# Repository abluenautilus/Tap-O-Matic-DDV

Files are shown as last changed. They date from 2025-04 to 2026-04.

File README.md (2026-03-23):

# Tap-O-Matic DDV

The Olivia Artz Modular Time Machine, version by Harry Richardson, modified by Blue Nautilus and the DivKid Discord, and finally tweaked heavily by Eris Fairbanks. We've come full circle folks!

This version modifies the [Tap-O-Matic version](https://github.com/cormallen/tap-o-matic) by HR in two ways:
<ul>
<li>It moves the pan pots down by 2mm. This makes the build much easier since the pan pots don't butt up against the sliders.</li>
<li>It moves the power header on the back so that it doesn't interfere with one of the jacks. This means you don't have to shave plastic off the jack.</li>
</ul>

**Eris's Software Notes:**
- Read heads are paired in order to utilize the PSRAM cache more effectively.
- The dynamics management system is drastically improved, utilizing a 4-point lookahead system per read-head pair.
- Filters used to be one-poles, now they're my own SVF implementation. Steeper cutoff, more resonance, more character.
- Code is a bit more readable and cleaner I think, constants and twiddle factors gathered up and commented.
- CPU usage is better, though extreme time variation might still cause frame drops? I haven't seen any, but that doesn't mean they aren't possible. Might be good to bump block size up to 8 if we notice any.
- Feedback can still distort. Dynamic range still isn't what I'd like it to be and probably never will be unless there's a hardware change to support 20vpp.

## Front Panel

All of the files for producing the panels are in the panel folder. This panel was fabricated by http://pcbway.com. It's a PCB panel using matte black solder mask:



## BOM

Our modified BOM is here:
https://docs.google.com/spreadsheets/d/1hPb3Es_wUxIoNBYNVZt8cKr9BfJMghtDLR-cnE-fVQ0/edit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

## Fabrication Instructions

The fabrication guide can be found here: 

https://docs.google.com/document/d/1D_RPgzVUW2ujZSJS9yKFKmFV2mPIwQp9BS7iKvg6IVI/edit?tab=t.0

## Build Instructions

The build guide can be found here: 

https://docs.google.com/document/d/1rPKsOXEx5abdQNxCypnp2nViSWlIubEysEng-fZd7tw/edit?tab=t.0

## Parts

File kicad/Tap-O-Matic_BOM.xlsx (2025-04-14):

Id | Designator | Footprint | Quantity | Designation | Part# | Link | Price/Ea | TotalPrice
1 | R6,R7,R1,R9,R8,R5,R4,R3,R2 | PTL45 | 9 | 10K | PTL30-15R0-104B2 | https://www.mouser.com/ProductDetail/Bourns/PTL30-15R0-104B2?qs=b8viKDOLiXa94D7vjOKn0w%3D%3D | 1.87 | 16.83
2 | RV7,RV14,RV13,RV12,RV11,RV10,RV9,RV8,RV6 | SongHuei_tall_trimmer | 9 | 10K |  | https://www.thonk.co.uk/shop/ttpots/ | 1.22 | 10.98
3 | SW2,SW1 | SALECOM_ES4-2_SPDT | 2 | SW_SPDT |  | https://www.thonk.co.uk/shop/ttpots/ | 1.84 | 3.68
4 | U1 | DaisySubmodule | 1 | DaisySubmodule |  | https://electro-smith.com/products/patch-submodule | 24 | 24
5 | RSPREAD1,RLPF1,RHPF1,RFB1,RTIME1 | Potentiometer_Alpha_RD901F-40-00D_Single_Vertical | 5 | 10K |  | https://www.thonk.co.uk/shop/alpha-9mm-pots/ | 2.15 | 10.75
6 | C5,C4,C3,C2,C1 | C_Disc_D3.8mm_W2.6mm_P2.50mm | 5 | 100n |  |  |  | 0
7 | J16 | PinHeader_2x05_P2.54mm_Vertical | 1 | Conn_02x05_Odd_Even |  |  |  | 0
8 | U5 | DIP-16_W7.62mm_Socket | 1 | DG408 |  |  |  | 0
9 | U4,U3,U2 | DIP-16_W7.62mm_Socket | 3 | 4051 |  |  |  | 0
10 | R18,R17,R16,R15,R14,R13,R12,R11,R10 | R_Axial_DIN0207_L6.3mm_D2.5mm_P7.62mm_Horizontal | 9 | 1K |  |  |  | 0
11 | OUT_R1,OUT_L1,IN_R1,IN_L1,LPF1,HPF1,FB1,TIME1,SPREAD1,CLOCK1,J9,J8,J7,J6,J5,J4,J3,J2,J1 | thonkiconn_fuzzySi | 19 | fuzzySI_thonkiconn |  |  |  | 0
12 | U2, U3, U4, U6 | DIP-16_W7.62mm_Socket | 4 | 16-pin DIP sockets |  |  |  | 0
13 | U1 | 2x5 header | 4 | 2x5 headers |  |  |  | 0
Total |  |  |  |  |  |  |  | 66.24

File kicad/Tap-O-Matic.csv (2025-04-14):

Id | Designator | Footprint | Quantity | Designation | Supplier and ref
1 | R6,R7,R1,R9,R8,R5,R4,R3,R2 | PTL45 | 9 | 10K
2 | RV7,RV14,RV13,RV12,RV11,RV10,RV9,RV8,RV6 | SongHuei_tall_trimmer | 9 | 10K
3 | SW2,SW1 | SALECOM_ES4-2_SPDT | 2 | SW_SPDT
4 | U1 | DaisySubmodule | 1 | DaisySubmodule
5 | RSPREAD1,RLPF1,RHPF1,RFB1,RTIME1 | Potentiometer_Alpha_RD901F-40-00D_Single_Vertical | 5 | 10K
6 | C5,C4,C3,C2,C1 | C_Disc_D3.8mm_W2.6mm_P2.50mm | 5 | 100n
7 | J16 | PinHeader_2x05_P2.54mm_Vertical | 1 | Conn_02x05_Odd_Even
8 | U5 | DIP-16_W7.62mm_Socket | 1 | DG408
9 | U4,U3,U2 | DIP-16_W7.62mm_Socket | 3 | 4051
10 | R18,R17,R16,R15,R14,R13,R12,R11,R10 | R_Axial_DIN0207_L6.3mm_D2.5mm_P7.62mm_Horizontal | 9 | 1K
11 | OUT_R1,OUT_L1,IN_R1,IN_L1,LPF1,HPF1,FB1,TIME1,SPREAD1,CLOCK1,J9,J8,J7,J6,J5,J4,J3,J2,J1 | thonkiconn_fuzzySi | 19 | fuzzySI_thonkiconn

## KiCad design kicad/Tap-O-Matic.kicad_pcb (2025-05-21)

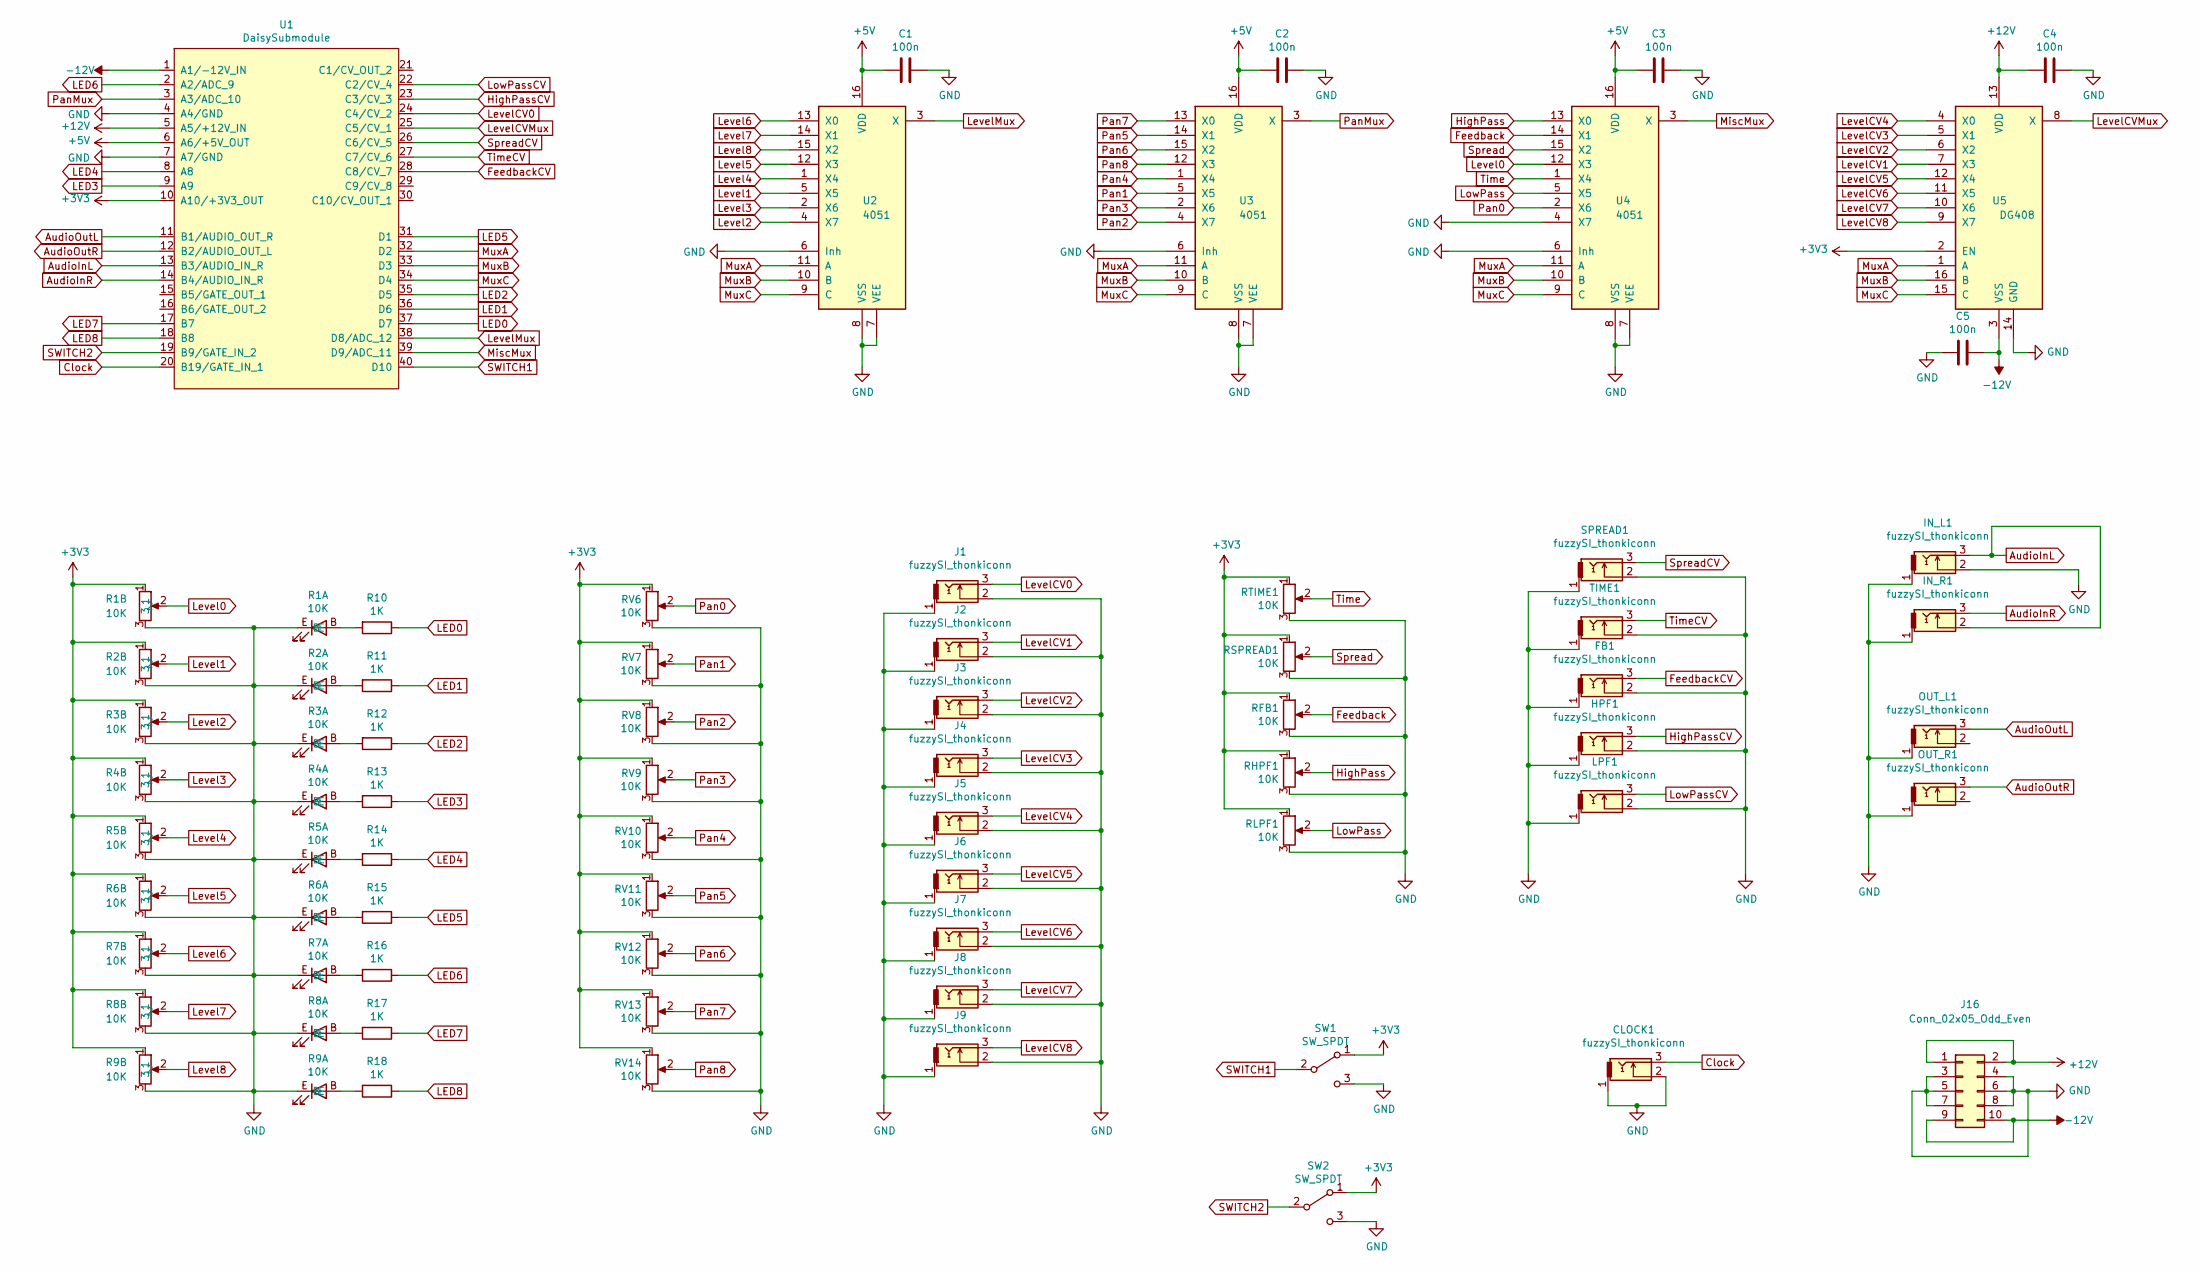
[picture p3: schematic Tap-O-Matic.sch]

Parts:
C1, C2, C3, C4, C5: 100n; C_Disc_D3.8mm_W2.6mm_P2.50mm
CLOCK1: fuzzySI_thonkiconn; thonkiconn_fuzzySi
FB1: fuzzySI_thonkiconn; thonkiconn_fuzzySi
HPF1: fuzzySI_thonkiconn; thonkiconn_fuzzySi
IN_L1: fuzzySI_thonkiconn; thonkiconn_fuzzySi
IN_R1: fuzzySI_thonkiconn; thonkiconn_fuzzySi
J1, J2, J3, J4, J5, J6, J7, J8, J9: fuzzySI_thonkiconn; thonkiconn_fuzzySi
J16: Conn_02x05_Odd_Even; PinHeader_2x05_P2.54mm_Vertical
LPF1: fuzzySI_thonkiconn; thonkiconn_fuzzySi
OUT_L1: fuzzySI_thonkiconn; thonkiconn_fuzzySi
OUT_R1: fuzzySI_thonkiconn; thonkiconn_fuzzySi
R1, R2, R3, R4, R5, R6, R7, R8, R9: 10K; PTL45
R10, R11, R12, R13, R14, R15, R16, R17, R18: 1K; R_Axial_DIN0207_L6.3mm_D2.5mm_P7.62mm_Horizontal
RFB1: 10K; Potentiometer_Alpha_RD901F-40-00D_Single_Vertical
RHPF1: 10K; Potentiometer_Alpha_RD901F-40-00D_Single_Vertical
RLPF1: 10K; Potentiometer_Alpha_RD901F-40-00D_Single_Vertical
RSPREAD1: 10K; Potentiometer_Alpha_RD901F-40-00D_Single_Vertical
RTIME1: 10K; Potentiometer_Alpha_RD901F-40-00D_Single_Vertical
RV6, RV7, RV8, RV9, RV10, RV11, RV12, RV13, RV14: 10K; SongHuei_tall_trimmer
SPREAD1: fuzzySI_thonkiconn; thonkiconn_fuzzySi
SW1, SW2: SW_SPDT; SALECOM_ES4-2_SPDT
TIME1: fuzzySI_thonkiconn; thonkiconn_fuzzySi
U1: DaisySubmodule
U2, U3, U4: 4051; DIP-16_W7.62mm_Socket
U5: DG408; DIP-16_W7.62mm_Socket

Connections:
+3V3: R1.1, R2.1, R3.1, R4.1, R5.1, R6.1, R7.1, R8.1, R9.1, RFB1.1, RHPF1.1, RLPF1.1, RSPREAD1.1, RTIME1.1, RV6.1, RV7.1, RV8.1, RV9.1, RV10.1, RV11.1, RV12.1, RV13.1, RV14.1, SW1.1 (A), SW2.1 (A), U1.10 (A10/+3V3_OUT), U5.2 (EN)
+5V: C1.2, C2.2, C3.2, U1.6 (A6/+5V_OUT), U2.16 (VDD), U3.16 (VDD), U4.16 (VDD)
+12V: C4.2, J16.1, J16.2, U1.5 (A5/+12V_IN), U5.13 (VDD)
-12V: C5.1, J16.9, J16.10, U1.1 (A1/-12V_IN), U5.3 (VSS)
AudioInL: IN_L1.3, IN_R1.2, U1.13 (B3/AUDIO_IN_R)
AudioInR: IN_R1.3, U1.14 (B4/AUDIO_IN_R)
AudioOutL: OUT_L1.3, U1.11 (B1/AUDIO_OUT_R)
AudioOutR: OUT_R1.3, U1.12 (B2/AUDIO_OUT_L)
Clock: CLOCK1.3, U1.20 (B19/GATE_IN_1)
Feedback: RFB1.2, U4.14 (X1)
FeedbackCV: FB1.3, U1.28 (C8/CV_7)
GND: C1.1, C2.1, C3.1, C4.1, C5.2, CLOCK1.1, CLOCK1.2, FB1.1, FB1.2, HPF1.1, HPF1.2, IN_L1.1, IN_L1.2, IN_R1.1, J1.1, J1.2, J2.1, J2.2, J3.1, J3.2, J4.1, J4.2, J5.1, J5.2, J6.1, J6.2, J7.1, J7.2, J8.1, J8.2, J9.1, J9.2, J16.3, J16.4, J16.5, J16.6, J16.7, J16.8, LPF1.1, LPF1.2, OUT_L1.1, OUT_R1.1, R1.3, R1.E, R2.3, R2.E, R3.3, R3.E, R4.3, R4.E, R5.3, R5.E, R6.3, R6.E, R7.3, R7.E, R8.3, R8.E, R9.3, R9.E, RFB1.3, RHPF1.3, RLPF1.3, RSPREAD1.3, RTIME1.3, RV6.3, RV7.3, RV8.3, RV9.3, RV10.3, RV11.3, RV12.3, RV13.3, RV14.3, SPREAD1.1, SPREAD1.2, SW1.3 (C), SW2.3 (C), TIME1.1, TIME1.2, U1.4 (A4/GND), U1.7 (A7/GND), U2.6 (Inh), U2.7 (VEE), U2.8 (VSS), U3.6 (Inh), U3.7 (VEE), U3.8 (VSS), U4.4 (X7), U4.6 (Inh), U4.7 (VEE), U4.8 (VSS), U5.14 (GND)
HighPass: RHPF1.2, U4.13 (X0)
HighPassCV: HPF1.3, U1.23 (C3/CV_3)
LED0: R10.1, U1.37 (D7)
LED1: R11.1, U1.36 (D6)
LED2: R12.1, U1.35 (D5)
LED3: R13.1, U1.9 (A9)
LED4: R14.1, U1.8 (A8)
LED5: R15.1, U1.31 (D1)
LED6: R16.1, U1.2 (A2/ADC_9)
LED7: R17.1, U1.17 (B7)
LED8: R18.1, U1.18 (B8)
Level0: R1.2, U4.12 (X3)
Level1: R2.2, U2.5 (X5)
Level2: R3.2, U2.4 (X7)
Level3: R4.2, U2.2 (X6)
Level4: R5.2, U2.1 (X4)
Level5: R6.2, U2.12 (X3)
Level6: R7.2, U2.13 (X0)
Level7: R8.2, U2.14 (X1)
Level8: R9.2, U2.15 (X2)
LevelCV0: J1.3, U1.24 (C4/CV_2)
LevelCV1: J2.3, U5.7 (X3)
LevelCV2: J3.3, U5.6 (X2)
LevelCV3: J4.3, U5.5 (X1)
LevelCV4: J5.3, U5.4 (X0)
LevelCV5: J6.3, U5.12 (X4)
LevelCV6: J7.3, U5.11 (X5)
LevelCV7: J8.3, U5.10 (X6)
LevelCV8: J9.3, U5.9 (X7)
LevelCVMux: U1.25 (C5/CV_1), U5.8 (X)
LevelMux: U1.38 (D8/ADC_12), U2.3 (X)
LowPass: RLPF1.2, U4.5 (X5)
LowPassCV: LPF1.3, U1.22 (C2/CV_4)
MiscMux: U1.39 (D9/ADC_11), U4.3 (X)
MuxA: U1.32 (D2), U2.11 (A), U3.11 (A), U4.11 (A), U5.1 (A)
MuxB: U1.33 (D3), U2.10 (B), U3.10 (B), U4.10 (B), U5.16 (B)
MuxC: U1.34 (D4), U2.9 (C), U3.9 (C), U4.9 (C), U5.15 (C)
unnamed: R1.B, R10.2
unnamed: R2.B, R11.2
unnamed: R3.B, R12.2
unnamed: R4.B, R13.2
unnamed: R5.B, R14.2
unnamed: R6.B, R15.2
unnamed: R7.B, R16.2
unnamed: R8.B, R17.2
unnamed: R9.B, R18.2
Pan0: RV6.2, U4.2 (X6)
Pan1: RV7.2, U3.5 (X5)
Pan2: RV8.2, U3.4 (X7)
Pan3: RV9.2, U3.2 (X6)
Pan4: RV10.2, U3.1 (X4)
Pan5: RV11.2, U3.14 (X1)
Pan6: RV12.2, U3.15 (X2)
Pan7: RV13.2, U3.13 (X0)
Pan8: RV14.2, U3.12 (X3)
PanMux: U1.3 (A3/ADC_10), U3.3 (X)
SWITCH1: SW1.2 (B), U1.40 (D10)
SWITCH2: SW2.2 (B), U1.19 (B9/GATE_IN_2)
Spread: RSPREAD1.2, U4.15 (X2)
SpreadCV: SPREAD1.3, U1.26 (C6/CV_5)
Time: RTIME1.2, U4.1 (X4)
TimeCV: TIME1.3, U1.27 (C7/CV_6)

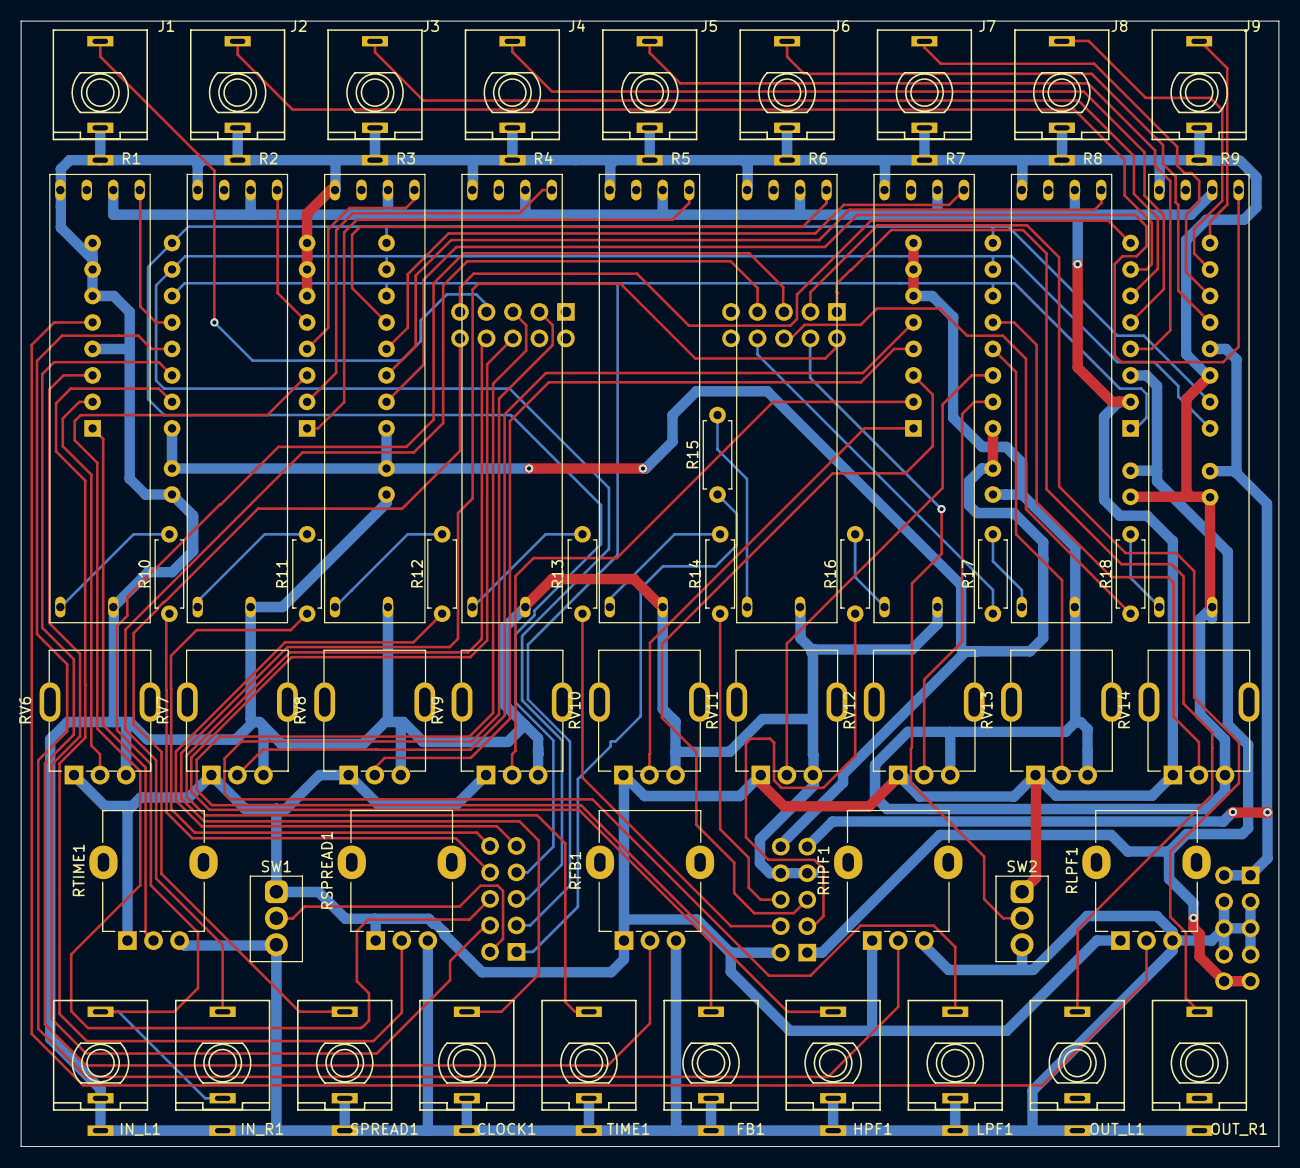
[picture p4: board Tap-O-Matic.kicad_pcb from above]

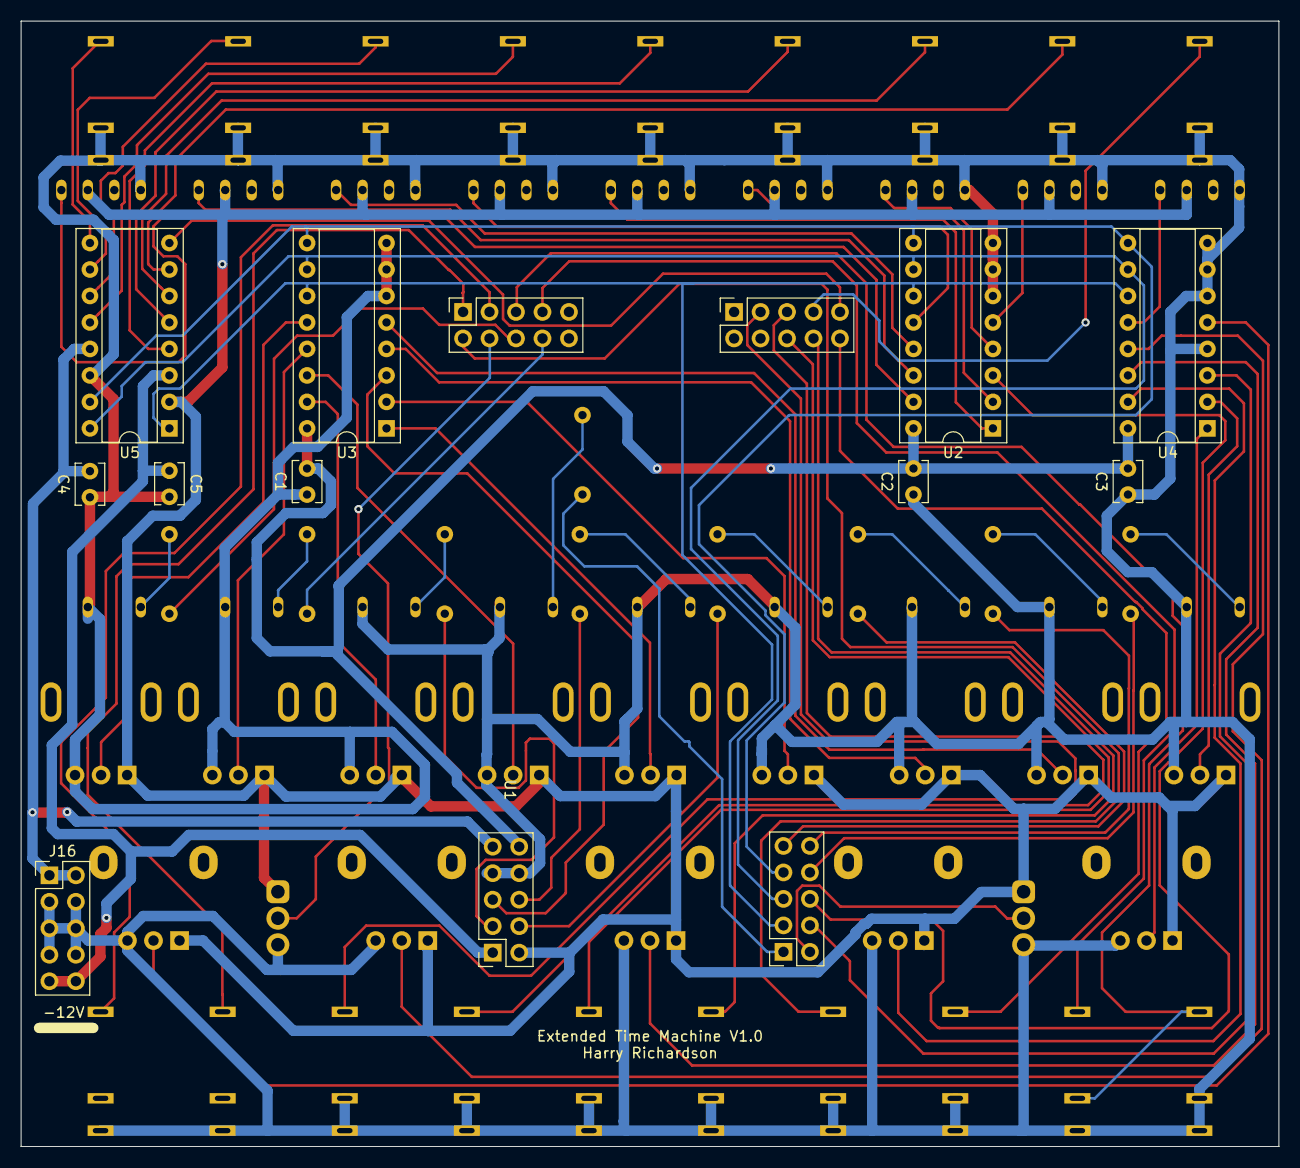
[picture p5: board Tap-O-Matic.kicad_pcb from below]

Board: 2 copper layers, 120.7 x 108.0 mm, 64 parts (11 on the bottom side), 74 nets.

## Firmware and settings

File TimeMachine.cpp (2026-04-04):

#include "daisy_patch_sm.h"
#include "daisysp.h"
#include "dsp.h"
#include "fast_math.h"
#include "time_machine_hardware.h"
#include "constants.h"

using namespace daisy;
using namespace oam;
using namespace time_machine;
using namespace std;

#define N_TAPS 9
#define TIME_SECONDS 150
#define CALIBRATION_SAMPLES 100
#define BUFFER_WIGGLE_ROOM_SAMPLES 1000

// #define LOGGING_ENABLED
// #define CPU_DIAGNOSTICS

// ------------------- //
// --- ERIS: TO DO --- //
// ------------------- //
// [x] steal soft clip from DSnomia (done, not using)
// [x] design custom multi-head-read lookadhead compressor
// [x] steal SVF from DSnomia (done, but using normal SVF)
// [x] run diagnostics and offset profiling
// [x] optimize CPU usage and attempt to reduce block size to eliminate hf noise
// [ ] hook up to balanced outs and do noise profiling
// [ ] figure out how to 3v calibrate time knob (and filter knobs?)
// [ ] make sure compressor starts kicking in before 0dB
// [ ] calibrate panning knobs

TimeMachineHardware hw;

// Setting Struct containing parameters we want to save to flash
// IMPORTANT: version field is at the where it is to maintain backwards compatibility
// with old calibration data that didn't have a version field. Old data will
// have garbage in the version field, which we detect and handle by resetting.
struct CvCalibrationData
{
	static constexpr uint32_t CURRENT_VERSION = 1;

	// Keep these fields in original order for backwards compatibility
	float timeCvOffset;
	float spreadCvOffset;
	float feedbackCvOffset;
	float lowpassCvOffset;
	float highpassCvOffset;
	float levelsCvOffset[N_TAPS];

	// Version field at here to not shift existing field offsets
	uint32_t version;

	// Additional fields go here so as to not throw off version field/struct ordering

	void Init()
	{
		timeCvOffset = 0.0;
		spreadCvOffset = 0.0;
		feedbackCvOffset = 0.0;
		lowpassCvOffset = 0.0;
		highpassCvOffset = 0.0;

		for (int i = 0 ; i < N_TAPS; i++)
		{
			levelsCvOffset[i] = 0.0;
		}

		version = CURRENT_VERSION;
	}

	bool IsValid() const
	{
		return version == CURRENT_VERSION;
	}

	// Overloading the != operator
	// This is necessary as this operator is used in the PersistentStorage source code
	bool operator!=(const CvCalibrationData& a) const
	{
		if (a.version != version) 					return true;
		if (a.timeCvOffset != timeCvOffset) 		return true;
		if (a.spreadCvOffset != spreadCvOffset) 	return true;
		if (a.feedbackCvOffset != feedbackCvOffset) return true;
		if (a.lowpassCvOffset != lowpassCvOffset) 	return true;
		if (a.highpassCvOffset != highpassCvOffset) return true;

		for (int i = 0; i < N_TAPS; i++)
		{
			if (a.levelsCvOffset[i] != levelsCvOffset[i]) return true;
		}

		return false;
    }
};


// Gather together all the values and Slew objects we need to handle a control
// consisting of a knob/slider and a CV input (optional).
class ControlHandler
{
public:
	char name[10];

	float cv;
	float cvOffset;
	Slew cvSlew;

	float knob;
	Slew knobSlew;

	float value;

	ControlHandler(const char *dumpName = "")
	{
		strncpy(name, dumpName, 9);

		cv = 0.0;
		cvSlew.Init(constants::SLEW_CV_COEF, constants::CV_NOISE_FLOOR);
		cvOffset = 0.0;

		knob = 0.0;
		knobSlew.Init(constants::SLEW_KNOB_COEF, constants::KNOB_NOISE_FLOOR);

		value = 0.0;
	}

	void SetDumpName(const char *dumpName)
	{
		strncpy(name, dumpName, sizeof(name));
	}

	void Dump()
	{
		hw.PrintLine(
			"%-10s   value:" FLT_FMT(5) "   knob:" FLT_FMT(5) "   cv:" FLT_FMT(5) "   offset:" FLT_FMT(5),
			name,
			FLT_VAR(5, value),
			FLT_VAR(5, knob),
			FLT_VAR(5, cv),
			FLT_VAR(5, cvOffset));
	}
};


// Interleaved stereo buffer for cache-optimized SDRAM access
// Layout: [L0][R0][L1][R1]... L/R at same position share cache lines
// This reduces cache misses by ~2x compared to separate L/R buffers
// Size: (samples per channel) * 2 (for stereo interleaving)
float DSY_SDRAM_BSS buffer[(48000 * TIME_SECONDS + BUFFER_WIGGLE_ROOM_SAMPLES) * 2]; // we should probably remove wiggle room? IDK, ain't broke don't fix it

ControlHandler time("time");
ControlHandler feedback("feedback");
ControlHandler spread("spread");
ControlHandler highpass("highpass");
ControlHandler lowpass("lowpass");
ControlHandler levels[N_TAPS];
ControlHandler pans[N_TAPS];

PersistentStorage<CvCalibrationData> CalibrationDataStorage(hw.qspi);
GateIn gate;
Led leds[N_TAPS];
GPIO feedbackModeSwitch;
GPIO filterPositionSwitch;

StereoTimeMachine timeMachine;
ClockRateDetector clockRateDetector;
ContSchmidt timeKnobSchmidt;
ContSchmidt timeCvSchmidt;

// delay setting LEDs for startup sequences
bool setLeds = false;

// Performance metrics.
CpuLoadMeter cpuMeter;
int droppedFrames = 0;


void updateControlHandlers()
{
	// condition feedback knob to have deadzone in the middle, add CV
	feedback.knob = fourPointWarp(1.0 - minMaxKnob(hw.GetFeedbackKnob(), constants::FEEDBACK_KNOB_DEADZONE));
	feedback.cv = clamp(hw.GetAdcValue(FEEDBACK_CV) - feedback.cvOffset, -1.0, 1.0);
	feedback.value = clamp(fourPointWarp(feedback.knobSlew.Process(feedback.knob)) * constants::FEEDBACK_GAIN_SCALE + feedback.cvSlew.Process(feedback.cv), 0, constants::FEEDBACK_MAX);

	// condition spread knob value to have deadzone in the middle, add CV
	spread.knob = fourPointWarp(1.0 - minMaxKnob(hw.GetSpreadKnob(), constants::SPREAD_KNOB_DEADZONE));
	spread.cv = clamp(hw.GetAdcValue(SPREAD_CV) - spread.cvOffset, -1.0, 1.0);
	spread.value = fourPointWarp(spread.knobSlew.Process(spread.knob)) + spread.cvSlew.Process(spread.cv);

	lowpass.knob = 1.0f - hw.GetLowpassKnob();
	lowpass.cv = clamp(hw.GetAdcValue(LOWPASS_CV) - lowpass.cvOffset, -1.0, 1.0);
	lowpass.value = clamp(lowpass.knobSlew.Process(lowpass.knob) + lowpass.cvSlew.Process(lowpass.cv), 0.0, 1.0);

	highpass.knob = 1.0f - hw.GetHighpassKnob();
	highpass.cv = clamp(hw.GetAdcValue(HIGHPASS_CV) - highpass.cvOffset, -1.0, 1.0);
	highpass.value = clamp(highpass.knobSlew.Process(highpass.knob) + highpass.cvSlew.Process(highpass.cv), 0.0, 1.0);

	// Handle the levels and pans.
	for (int i = 0; i < N_TAPS; i++)
	{
		ControlHandler &s = levels[i];
		s.knob = minMaxSlider(1.0 - hw.GetLevelSlider(i));
		s.cv = clamp((hw.GetLevelCV(i)) - s.cvOffset, -1.0, 1.0);
		s.value = clamp(s.knobSlew.Process(s.knob) + s.cvSlew.Process(s.cv), 0.0, 1.0);

		ControlHandler &p = pans[i];
		p.knob = hw.GetPanKnob(i);
		p.value = clamp(p.knobSlew.Process(p.knob), -1.0, 1.0);
	}

	// Handle the time stuff, which is a bit more involved.
	time.knob = minMaxKnob(1.0 - hw.GetTimeKnob(), constants::TIME_KNOB_DEADZONE);
	time.cv = clamp(hw.GetAdcValue(TIME_CV) - time.cvOffset, -1.0, 1.0);

	// calculate time based on clock if present, otherwise simple time
	time.value = 0.0;
	if (clockRateDetector.GetInterval() > 0.0)
	{
		// Quantized steps for clock sync: knob controls octave divisions, CV adds/subtracts octaves
		float timeCoef = fast_exp2((timeKnobSchmidt.Process((1.0 - time.knob) * constants::CLOCK_KNOB_STEPS)) + (timeCvSchmidt.Process(time.cv * constants::CLOCK_CV_STEPS))) / constants::CLOCK_CENTER_DIVISOR;
		time.value = clockRateDetector.GetInterval() / timeCoef;

		// make sure time is a power of two less than the max time available in the buffer
		while(time.value > TIME_SECONDS) time.value *= 0.5;
	}
	else
	{
		// time quadratic with knob (finer control at short times), scaled v/oct style with CV
		float knob = time.knobSlew.Process(time.knob);
		time.value = knob * knob * constants::TIME_MAX_SECONDS / fast_exp2(time.cvSlew.Process(time.cv) * constants::TIME_CV_OCTAVE_RANGE);
	}

	// force time down to a max value (taking whichever is lesser, the max or the time)
	time.value = std::min((float)TIME_SECONDS, time.value);
}


// called every N samples (search for SetAudioBlockSize)
void audioCallback(AudioHandle::InputBuffer in, AudioHandle::OutputBuffer out, size_t size)
{
#ifdef CPU_DIAGNOSTICS
	// cpu meter measurements start
	cpuMeter.OnBlockStart();
	droppedFrames++;
#endif

	// process controls at the ADC level.
	hw.ProcessAllControls();

	// Then we can use those values when updating our handlers.
	updateControlHandlers();

	// Set global time machine parameters (feedback, filters, modes)
	timeMachine.Set(feedback.value, highpass.value, lowpass.value, feedbackModeSwitch.Read(), filterPositionSwitch.Read());

	// Set dry tap (tap 0) with pan
	float dryPanL, dryPanR;
	panToVolume(hw.GetPanKnob(0), &dryPanL, &dryPanR);
	timeMachine.SetDryTap(levels[0].value * dryPanL, levels[0].value * dryPanR);

	// Set delay taps (taps 1-8) with delay, pan, and blur
	for (int i = 1; i < N_TAPS; i++)
	{
		float tapPanL, tapPanR;
		panToVolume(hw.GetPanKnob(i), &tapPanL, &tapPanR);

		float delay = spreadTaps((i / (float)(N_TAPS - 1)), spread.value) * time.value;
		float blur = max(0.0f, feedback.value - 1.0f);

		timeMachine.SetDelayTap(i, delay, tapPanL * levels[i].value, tapPanR * levels[i].value, blur);
	}

	for (size_t i = 0; i < size; i++)
	{
		// process gate for clock rate detector at audio rate (per-sample) so it calculates clock correctly
		clockRateDetector.Process(hw.gate_in_1.State());

		// process input into time machine
		float* output = timeMachine.Process(in[0][i], in[1][i]);

		// set hardware output to time machine output
		out[0][i] = output[0];
		out[1][i] = output[1];
	}

#ifdef CPU_DIAGNOSTICS
	//cpu meter measurement stop
	cpuMeter.OnBlockEnd();
	droppedFrames--;
#endif
}


bool isCvCloseToZero(float val)
{
	return (val > -constants::CV_ZERO_THRESHOLD) && (val < constants::CV_ZERO_THRESHOLD);
}


bool shouldCalibrate()
{
	hw.PrintLine("=== Calibration Check ===");

	float gateState = hw.gate_in_1.State() ? 1.0f : 0.0f;
	hw.PrintLine("Gate: " FLT_FMT(3) " (need HIGH)", FLT_VAR(3, gateState));
	if (!hw.gate_in_1.State()) return false;

	// CV inputs need to be close to zero
	float spreadCv = hw.GetAdcValue(SPREAD_CV);
	float timeCv = hw.GetAdcValue(TIME_CV);
	float feedbackCv = hw.GetAdcValue(FEEDBACK_CV);
	float highpassCv = hw.GetAdcValue(HIGHPASS_CV);
	float lowpassCv = hw.GetAdcValue(LOWPASS_CV);
	float levelDryCv = hw.GetAdcValue(LEVEL_DRY_CV);

	hw.PrintLine("CV inputs (need ~0, threshold " FLT_FMT(3) "):", FLT_VAR(3, constants::CV_ZERO_THRESHOLD));
	hw.PrintLine("  Spread:   " FLT_FMT(4) " %s", FLT_VAR(4, spreadCv), isCvCloseToZero(spreadCv) ? "OK" : "FAIL");
	hw.PrintLine("  Time:     " FLT_FMT(4) " %s", FLT_VAR(4, timeCv), isCvCloseToZero(timeCv) ? "OK" : "FAIL");
	hw.PrintLine("  Feedback: " FLT_FMT(4) " %s", FLT_VAR(4, feedbackCv), isCvCloseToZero(feedbackCv) ? "OK" : "FAIL");
	hw.PrintLine("  Highpass: " FLT_FMT(4) " %s", FLT_VAR(4, highpassCv), isCvCloseToZero(highpassCv) ? "OK" : "FAIL");
	hw.PrintLine("  Lowpass:  " FLT_FMT(4) " %s", FLT_VAR(4, lowpassCv), isCvCloseToZero(lowpassCv) ? "OK" : "FAIL");
	hw.PrintLine("  LevelDry: " FLT_FMT(4) " %s", FLT_VAR(4, levelDryCv), isCvCloseToZero(levelDryCv) ? "OK" : "FAIL");

	if (!isCvCloseToZero(spreadCv)) return false;
	if (!isCvCloseToZero(timeCv)) return false;
	if (!isCvCloseToZero(feedbackCv)) return false;
	if (!isCvCloseToZero(highpassCv)) return false;
	if (!isCvCloseToZero(lowpassCv)) return false;
	if (!isCvCloseToZero(levelDryCv)) return false;

	// Knobs need to be fully CCW
	float timeKnob = hw.GetTimeKnob();
	float spreadKnob = hw.GetSpreadKnob();
	float feedbackKnob = hw.GetFeedbackKnob();
	float lowpassKnob = hw.GetLowpassKnob();
	float highpassKnob = hw.GetHighpassKnob();

	hw.PrintLine("Knobs (need <0.05 for CCW):");
	hw.PrintLine("  Time:     " FLT_FMT(4) " %s", FLT_VAR(4, timeKnob), minMaxKnob(1.0 - timeKnob) >= 0.95 ? "OK" : "FAIL");
	hw.PrintLine("  Spread:   " FLT_FMT(4) " %s", FLT_VAR(4, spreadKnob), minMaxKnob(1.0 - spreadKnob) >= 0.95 ? "OK" : "FAIL");
	hw.PrintLine("  Feedback: " FLT_FMT(4) " %s", FLT_VAR(4, feedbackKnob), minMaxKnob(1.0 - feedbackKnob) >= 0.95 ? "OK" : "FAIL");
	hw.PrintLine("  Lowpass:  " FLT_FMT(4) " %s", FLT_VAR(4, lowpassKnob), minMaxKnob(1.0 - lowpassKnob) >= 0.95 ? "OK" : "FAIL");
	hw.PrintLine("  Highpass: " FLT_FMT(4) " %s", FLT_VAR(4, highpassKnob), minMaxKnob(1.0 - highpassKnob) >= 0.95 ? "OK" : "FAIL");

	if (minMaxKnob(1.0 - timeKnob) < 0.95) return false;
	if (minMaxKnob(1.0 - spreadKnob) < 0.95) return false;
	if (minMaxKnob(1.0 - feedbackKnob) < 0.95) return false;
	if (minMaxKnob(1.0 - lowpassKnob) < 0.95) return false;
	if (minMaxKnob(1.0 - highpassKnob) < 0.95) return false;

	// Sliders and level CVs
	hw.PrintLine("Sliders (need <0.05) and Level CVs (need ~0):");
	for (int i = 0; i < N_TAPS; i++)
	{
		float levelCv = hw.GetLevelCV(i);
		float levelSlider = hw.GetLevelSlider(i);
		bool cvOk = isCvCloseToZero(levelCv);
		bool sliderOk = minMaxSlider(1.0 - levelSlider) >= 0.95;

		hw.PrintLine("  [%d] CV:" FLT_FMT(4) " %s  Slider:" FLT_FMT(4) " %s",
			i, FLT_VAR(4, levelCv), cvOk ? "OK" : "FAIL",
			FLT_VAR(4, levelSlider), sliderOk ? "OK" : "FAIL");

		if (!cvOk) return false;
		if (!sliderOk) return false;
	}

	hw.PrintLine("=== All checks passed - calibrating ===");
	return true;
}


void calibrate(CvCalibrationData &saved, int ledSeqDelay)
{
	// do reverse LED startup sequence while
	// checking that we definitely want to calibrate
	for (int i = 0; i < (5000 / ledSeqDelay); i++)
	{
		for (int j = 0; j < N_TAPS; j++)
		{
			leds[j].Set(j == ((N_TAPS - 1) - (i % N_TAPS)) ? 1.0 : 0.0);
			leds[j].Update();
		}

		System::Delay(ledSeqDelay);
		if (!shouldCalibrate()) return;
	}

	saved.Init();

	hw.PrintLine("Starting calibration");

	// perform calibration routine
	for (int i = 0; i < CALIBRATION_SAMPLES; i++)
	{
		// accumulate raw ADC values (not ControlHandler.cv which has offsets applied)
		saved.timeCvOffset += hw.GetAdcValue(TIME_CV);
		saved.spreadCvOffset += hw.GetAdcValue(SPREAD_CV);
		saved.feedbackCvOffset += hw.GetAdcValue(FEEDBACK_CV);
		saved.lowpassCvOffset += hw.GetAdcValue(LOWPASS_CV);
		saved.highpassCvOffset += hw.GetAdcValue(HIGHPASS_CV);

		for (int j = 0; j < N_TAPS; j++)
		{
			saved.levelsCvOffset[j] += hw.GetLevelCV(j);
		}

		// wait 1ms
		System::Delay(1);

		// set LEDs
		for (int ledIndex = 0; ledIndex < N_TAPS; ledIndex++)
		{
			leds[ledIndex].Set(i % (N_TAPS - 1) < 4 ? 1.0f : 0.0f);
			leds[ledIndex].Update();
		}
	}

	// divide CVs by number of samples taken to get average

	float n = (float) CALIBRATION_SAMPLES;
	saved.timeCvOffset = saved.timeCvOffset / n;
	saved.spreadCvOffset = saved.spreadCvOffset / n;
	saved.feedbackCvOffset = saved.feedbackCvOffset / n;
	saved.lowpassCvOffset = saved.lowpassCvOffset / n;
	saved.highpassCvOffset = saved.highpassCvOffset / n;

	for (int i = 0; i < N_TAPS; i++)
	{
		saved.levelsCvOffset[i] = saved.levelsCvOffset[i] / n;
	}

	// Validate calibration
	// Reject if any offset is not close to zero
	// This catches cases where voltage was patched during calibration
	bool valid = true;

	if (!isCvCloseToZero(saved.timeCvOffset)) valid = false;
	if (!isCvCloseToZero(saved.spreadCvOffset)) valid = false;
	if (!isCvCloseToZero(saved.feedbackCvOffset)) valid = false;
	if (!isCvCloseToZero(saved.lowpassCvOffset)) valid = false;
	if (!isCvCloseToZero(saved.highpassCvOffset)) valid = false;

	for (int i = 0; i < N_TAPS; i++)
	{
		if (!isCvCloseToZero(saved.levelsCvOffset[i])) valid = false;
	}

	if (!valid)
	{
		hw.PrintLine("Calibration rejected: offsets out of range");
		saved.Init();  // Reset to defaults

		// Flash all LEDs to indicate error
		for (int i = 0; i < 6; i++)
		{
			float brightness = (i % 2 == 0) ? 1.0f : 0.0f;
			for (int j = 0; j < N_TAPS; j++)
			{
				leds[j].Set(brightness);
				leds[j].Update();
			}
			System::Delay(200);
		}
		return;
	}

	hw.PrintLine("Calibration successful");

	// save calibration data
	CalibrationDataStorage.Save();
}

void applyCalibrationOffsets(const CvCalibrationData &calibration)
{
	time.cvOffset = calibration.timeCvOffset;
	spread.cvOffset = calibration.spreadCvOffset;
	feedback.cvOffset = calibration.feedbackCvOffset;
	highpass.cvOffset = calibration.highpassCvOffset;
	lowpass.cvOffset = calibration.lowpassCvOffset;

	for (int i = 0; i < N_TAPS; i++)
	{
		levels[i].cvOffset = calibration.levelsCvOffset[i];
	}
}


// Log raw ADC values for deadzone analysis
// Run this while moving controls to their min/max positions to determine optimal deadzones
void logControlDiagnostics()
{
	hw.PrintLine("=== CONTROL DIAGNOSTICS (raw ADC values) ===");
	hw.PrintLine("Move controls to min/max to see endpoint behavior");
	hw.PrintLine("");

	// Main knobs: raw values
	hw.PrintLine("KNOBS (raw):");
	hw.PrintLine("  Time:     " FLT_FMT(6), FLT_VAR(6, hw.GetTimeKnob()));
	hw.PrintLine("  Spread:   " FLT_FMT(6), FLT_VAR(6, hw.GetSpreadKnob()));
	hw.PrintLine("  Feedback: " FLT_FMT(6), FLT_VAR(6, hw.GetFeedbackKnob()));
	hw.PrintLine("  Lowpass:  " FLT_FMT(6), FLT_VAR(6, hw.GetLowpassKnob()));
	hw.PrintLine("  Highpass: " FLT_FMT(6), FLT_VAR(6, hw.GetHighpassKnob()));
	hw.PrintLine("");

	// CV inputs: raw values
	hw.PrintLine("CV INPUTS (raw, should be ~0 when unpatched):");
	hw.PrintLine("  Time CV:     " FLT_FMT(6), FLT_VAR(6, hw.GetAdcValue(TIME_CV)));
	hw.PrintLine("  Spread CV:   " FLT_FMT(6), FLT_VAR(6, hw.GetAdcValue(SPREAD_CV)));
	hw.PrintLine("  Feedback CV: " FLT_FMT(6), FLT_VAR(6, hw.GetAdcValue(FEEDBACK_CV)));
	hw.PrintLine("  Lowpass CV:  " FLT_FMT(6), FLT_VAR(6, hw.GetAdcValue(LOWPASS_CV)));
	hw.PrintLine("  Highpass CV: " FLT_FMT(6), FLT_VAR(6, hw.GetAdcValue(HIGHPASS_CV)));
	hw.PrintLine("  Dry CV:      " FLT_FMT(6), FLT_VAR(6, hw.GetAdcValue(LEVEL_DRY_CV)));
	hw.PrintLine("");

	// Level sliders: raw values
	hw.PrintLine("SLIDERS (raw):");
	for (int i = 0; i < N_TAPS; i++)
	{
		hw.PrintLine("  Slider %d: " FLT_FMT(6), i, FLT_VAR(6, hw.GetLevelSlider(i)));
	}
	hw.PrintLine("");

	// Level CVs: raw values
	hw.PrintLine("LEVEL CVs (raw):");
	for (int i = 0; i < N_TAPS; i++)
	{
		hw.PrintLine("  Level CV %d: " FLT_FMT(6), i, FLT_VAR(6, hw.GetLevelCV(i)));
	}
	hw.PrintLine("");

	// Pan knobs: raw values
	hw.PrintLine("PAN KNOBS (raw):");
	for (int i = 0; i < N_TAPS; i++)
	{
		hw.PrintLine("  Pan %d: " FLT_FMT(6), i, FLT_VAR(6, hw.GetPanKnob(i)));
	}
	hw.PrintLine("");
}
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
int main(void)
{
	// init time machine hardware
  hw.Init();
	hw.StartLog();

	hw.SetAudioBlockSize(5); // number of samples handled per callback


	Pin gatePin = CLOCK;
	gate.Init(gatePin);

	// initialize LEDs
	leds[0].Init(LED_DRY, false);
	leds[1].Init(LED_1, false);
	leds[2].Init(LED_2, false);
	leds[3].Init(LED_3, false);
	leds[4].Init(LED_4, false);
	leds[5].Init(LED_5, false);
	leds[6].Init(LED_6, false);
	leds[7].Init(LED_7, false);
	leds[8].Init(LED_8, false);

	for (int i = 0; i < N_TAPS; i++)
	{
		char buf[10];
		sprintf(buf, "pan_%d", i);
		pans[i].SetDumpName(buf);

		sprintf(buf, "level_%d", i);
		levels[i].SetDumpName(buf);
	}

  // Initialize our switch.
  feedbackModeSwitch.Init(FEEDBACK_MODE_SWITCH, GPIO::Mode::INPUT, GPIO::Pull::PULLUP);
	filterPositionSwitch.Init(FILTER_POSITION_SWITCH, GPIO::Mode::INPUT, GPIO::Pull::PULLUP);

	// set sample rate
	hw.SetAudioSampleRate(SaiHandle::Config::SampleRate::SAI_48KHZ);

	// init clock rate detector
	clockRateDetector.Init(hw.AudioSampleRate());

	// init time machine with interleaved stereo buffer
  timeMachine.Init(hw.AudioSampleRate(), TIME_SECONDS + (((float) BUFFER_WIGGLE_ROOM_SAMPLES) * 0.5 / hw.AudioSampleRate()), buffer);

	// load calibration data, using sensible defaults
	CvCalibrationData defaults;
	defaults.Init();

	CalibrationDataStorage.Init(defaults);
	CvCalibrationData &savedCalibrationData = CalibrationDataStorage.GetSettings();

	// Log calibration state and handle version mismatch
	auto storageState = CalibrationDataStorage.GetState();
	if (storageState == PersistentStorage<CvCalibrationData>::State::FACTORY)
	{
		hw.PrintLine("First boot - using factory defaults");
	}
	else if (!savedCalibrationData.IsValid())
	{
		// Version mismatch: old or corrupted calibration data
		// Reset to defaults to avoid garbage values
		hw.PrintLine("Calibration data version mismatch (got %lu, expected %lu) - resetting to defaults",
			savedCalibrationData.version, CvCalibrationData::CURRENT_VERSION);
		savedCalibrationData.Init();
		CalibrationDataStorage.Save();
	}
	else
	{
		hw.PrintLine("Loaded user calibration data (version %lu)", savedCalibrationData.version);
	}

	// Apply calibration offsets BEFORE starting audio so audio callback
	// has correct offsets from the first sample
	applyCalibrationOffsets(savedCalibrationData);

	// init cpu meter
	cpuMeter.Init(hw.AudioSampleRate(), hw.AudioBlockSize());

	// start time machine hardware audio and logging
  hw.StartAudio(audioCallback);

	// LED startup sequence
	int ledSeqDelay = 100;
	for(int i = 0; i < N_TAPS; i++)
	{
		for(int j = 0; j < N_TAPS; j++)
		{
			leds[j].Set(j == i ? 1.0 : 0.0);
			leds[j].Update();
		}

		System::Delay(ledSeqDelay);
	}

	if (shouldCalibrate())
	{
		calibrate(savedCalibrationData, ledSeqDelay);
		// Re-apply new calibration offsets after calibration
		applyCalibrationOffsets(savedCalibrationData);
	}

	setLeds = true;

	// FPU busywork state keeps the FPU active between audio interrupts so
	// that hopefully the noise is less bad????
	static volatile float fpu_dummy = 1.0f;
	uint32_t last_log_ms = 0;
	uint32_t last_led_ms = 0;

	while (true)
	{
		uint32_t now = System::GetNow();

		// Update LEDs at ~1kHz from the main loop (not the audio interrupt) to
		// avoid FPU lazy-stacking corruption of the Led::Update() pwm accumulator.
		if (now - last_led_ms >= 1)
		{
			if (setLeds)
			{
				for (int i = 0; i < N_TAPS; i++)
				{
					leds[i].Set(timeMachine.GetTapLoudness(i));
					leds[i].Update();
				}
			}
			last_led_ms = now;
		}

#ifdef LOGGING_ENABLED
		if (now - last_log_ms >= 500)
		{
			logState();
			last_log_ms = now;
		}
#endif

		// Keep FPU active to level power draw. volatile prevents optimization.
		// Multiplier kept near 1.0 to avoid NaN/Inf accumulation over time.
		fpu_dummy = fpu_dummy * 0.99999f + 0.00001f;
	}
}

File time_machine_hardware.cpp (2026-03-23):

#include "time_machine_hardware.h"
#include <vector>

namespace oam
{
namespace time_machine
{
    /** Const definitions */
    static constexpr Pin DUMMYPIN        = Pin(PORTX, 0);
    static constexpr Pin PIN_ADC_CTRL_1  = Pin(PORTA, 3);
    static constexpr Pin PIN_ADC_CTRL_2  = Pin(PORTA, 6);
    static constexpr Pin PIN_ADC_CTRL_3  = Pin(PORTA, 2);
    static constexpr Pin PIN_ADC_CTRL_4  = Pin(PORTA, 7);
    static constexpr Pin PIN_ADC_CTRL_5  = Pin(PORTB, 1);
    static constexpr Pin PIN_ADC_CTRL_6  = Pin(PORTC, 4);
    static constexpr Pin PIN_ADC_CTRL_7  = Pin(PORTC, 0);
    static constexpr Pin PIN_ADC_CTRL_8  = Pin(PORTC, 1);
    static constexpr Pin PIN_ADC_CTRL_9  = Pin(PORTA, 1);
    static constexpr Pin PIN_ADC_CTRL_10 = Pin(PORTA, 0);
    static constexpr Pin PIN_ADC_CTRL_11 = Pin(PORTC, 2);
    static constexpr Pin PIN_ADC_CTRL_12 = Pin(PORTC, 3);
    static constexpr Pin PIN_USER_LED    = Pin(PORTC, 7);

    const Pin kPinMap[4][10] = {
        /** Header Bank A */
        {
            DUMMYPIN,        /**< A1  - -12V Power Input */
            {PORTA, 1},  /**< A2  - UART1 Rx */
            {PORTA, 0},  /**< A3  - UART1 Tx */
            DUMMYPIN,        /**< A4  - GND */
            DUMMYPIN,        /**< A5  - +12V Power Input */
            DUMMYPIN,        /**< A6  - +5V Power Output */
            DUMMYPIN,        /**< A7  - GND */
            {PORTB, 14}, /**< A8  - USB DM */
            {PORTB, 15}, /**< A9  - USB DP */
            DUMMYPIN,        /**< A10 - +3V3 Power Output */
        },
        /** Header Bank B */
        {
            DUMMYPIN,        /**< B1  - Audio Out Right */
            DUMMYPIN,        /**< B2  - Audio Out Left*/
            DUMMYPIN,        /**< B3  - Audio In Right */
            DUMMYPIN,        /**< B4  - Audio In Left */
            {PORTC, 13}, /**< B5  - GATE OUT 1 */
            {PORTC, 14}, /**< B6  - GATE OUT 2 */
            {PORTB, 8},  /**< B7  - I2C1 SCL */
            {PORTB, 9},  /**< B8  - I2C1 SDA */
            {PORTG, 14}, /**< B9  - GATE IN 2 */
            {PORTG, 13}, /**< B10 - GATE IN 1 */
        },
        /** Header Bank C */
        {
            {PORTA, 5}, /**< C1  - CV Out 2 */
            PIN_ADC_CTRL_4, /**< C2  - CV In 4 */
            PIN_ADC_CTRL_3, /**< C3  - CV In 3 */
            PIN_ADC_CTRL_2, /**< C4  - CV In 2 */
            PIN_ADC_CTRL_1, /**< C5  - CV In 1 */
            PIN_ADC_CTRL_5, /**< C6  - CV In 5 */
            PIN_ADC_CTRL_6, /**< C7  - CV In 6 */
            PIN_ADC_CTRL_7, /**< C8  - CV In 7 */
            PIN_ADC_CTRL_8, /**< C9  - CV In 8 */
            {PORTA, 4}, /**< C10 - CV Out 1 */
        },
        /** Header Bank D */
        {
            {PORTB, 4},  /**< D1  - SPI2 CS */
            {PORTC, 11}, /**< D2  - SDMMC D3 */
            {PORTC, 10}, /**< D3  - SDMMC D2*/
            {PORTC, 9},  /**< D4  - SDMMC D1*/
            {PORTC, 8},  /**< D5  - SDMMC D0 */
            {PORTC, 12}, /**< D6  - SDMMC CK */
            {PORTD, 2},  /**< D7  - SDMMC CMD */
            {PORTC, 2},  /**< D8  - SPI2 MISO */
            {PORTC, 3},  /**< D9  - SPI2 MOSI */
            {PORTD, 3},  /**< D10 - SPI2 SCK  */
        },
    };
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

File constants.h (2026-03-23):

#pragma once

namespace constants {

// -----------------------------------------------------------------------------
// Hardware / ADC Compensation
// -----------------------------------------------------------------------------

// Knob/slider deadzone compensation
constexpr float DEFAULT_KNOB_DEADZONE = 0.002f;
constexpr float FEEDBACK_KNOB_DEADZONE = 0.028f;
constexpr float SPREAD_KNOB_DEADZONE = 0.0008f;
constexpr float TIME_KNOB_DEADZONE = 0.0008f;

// CV calibration threshold
constexpr float CV_ZERO_THRESHOLD = 0.05f;

// -----------------------------------------------------------------------------
// Slew / Smoothing Rates
// -----------------------------------------------------------------------------
// Slew coefficient determines smoothing speed.
// Use msToSlewCoef() to convert milliseconds to coefficient at 48kHz.

constexpr float SAMPLE_RATE = 48000.0f;

// Convert time constant in milliseconds to slew coefficient
// Formula: coef = 1000 / (ms * sampleRate)
constexpr float msToSlewCoef(float ms) {
    return 1000.0f / (ms * SAMPLE_RATE);
}

constexpr float SLEW_DEFAULT_COEF = msToSlewCoef(21.0f);   // 21ms
constexpr float SLEW_KNOB_COEF = msToSlewCoef(21.0f);      // 21ms
constexpr float SLEW_CV_COEF = msToSlewCoef(4.0f);         // 4ms
constexpr float SLEW_FEEDBACK_COEF = msToSlewCoef(2.0f);   // 2ms
constexpr float SLEW_AMP_ATTACK = 1.0f;                    // Instant (coef=1.0)
constexpr float SLEW_AMP_RELEASE = msToSlewCoef(210.0f);   // 210ms

constexpr float CV_NOISE_FLOOR = 0.005f;                   // Ignore CV changes < 0.5%
constexpr float KNOB_NOISE_FLOOR = 0.005f;                 // Ignore knob changes < 0.5%

// Settle detection: samples to wait before considering input stable
// 96 samples at 48kHz = 2ms
constexpr int SLEW_SETTLE_SAMPLES = 96;

// Sentinel value indicating slew coefficients need recalculation
constexpr float SLEW_COEF_UNINITIALIZED = -100.0f;

// DC blocker coefficient
// At 48kHz: time constant ~2 seconds, cutoff ~0.08Hz
constexpr float DC_BLOCKER_COEF = 0.00001f;

// -----------------------------------------------------------------------------
// Limiter / Dynamics
// -----------------------------------------------------------------------------

// LoudnessDetector asymmetric envelope timings
// Fast attack to catch transients before they arrive (must be < lookahead time)
// Slow release to avoid pumping artifacts
constexpr float LOUDNESS_ATTACK_MS = 3.0f;           // Fast attack (< 10ms lookahead)
constexpr float LOUDNESS_RELEASE_MS = 75.0f;         // Slow release for smoothness

// Feedback ceiling dynamically caps effective feedback to keep buffer bounded
constexpr float FB_TARGET_LEVEL = 1.0f;              // Buffer stabilizes around +/-1.0

// Number of sample points to check in lookahead window (performance vs accuracy)
constexpr int LOOKAHEAD_SAMPLE_POINTS = 4;

// -----------------------------------------------------------------------------
// ReadHead / Crossfade
// -----------------------------------------------------------------------------

// Crossfade time when delay tap parameters change
// delta = 5.0/sampleRate, which gives 200ms crossfade
constexpr float CROSSFADE_RATE = 5.0f;               // Results in ~200ms at 48kHz

// -----------------------------------------------------------------------------
// Control Response Curves
// -----------------------------------------------------------------------------

// Input 0.45-0.55 maps to constant 0.5 output (10% deadzone at center)
constexpr float WARP_POINT_B_IN = 0.45f;             // Start of center plateau
constexpr float WARP_POINT_B_OUT = 0.5f;
constexpr float WARP_POINT_C_IN = 0.55f;             // End of center plateau
constexpr float WARP_POINT_C_OUT = 0.5f;

constexpr float SPREAD_EXPONENT = 2.5f;

// 1.0 = constant power, 1.5 = slightly more aggressive center cut
constexpr float PAN_LAW_EXPONENT = 1.5f;

// 0.0 = no resonance (gentle 12dB/oct), 0.3 = tight response (~2-3dB peak)
constexpr float FILTER_RESONANCE = 0.3f;

constexpr float SCHMIDT_HYSTERESIS = 0.333f;

// -----------------------------------------------------------------------------
// Time / Clock Sync
// -----------------------------------------------------------------------------

// Clock sync quantization steps
constexpr int CLOCK_KNOB_STEPS = 12;                 // Knob: 12 steps = +/-6 octaves
constexpr int CLOCK_CV_STEPS = 10;                   // CV: 10 steps = +/-5 octaves
constexpr float CLOCK_CENTER_DIVISOR = 64.0f;        // 2^6, centers knob at 1x

// Free-running time parameters
constexpr float TIME_MAX_SECONDS = 8.0f;             // Max delay at knob=1.0
constexpr float TIME_KNOB_CURVE = 2.0f;              // Quadratic for fine control at short times
constexpr float TIME_CV_OCTAVE_RANGE = 5.0f;         // CV scales +/-5 octaves (32x range)
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

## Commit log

2025-04-23 full changes for second iteration
    [Tap-O-Matic-B_Cu.gbr, Tap-O-Matic-B_Mask.gbr, Tap-O-Matic-B_Paste.gbr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]
2025-05-21 various updates
    [Tap-O-Matic.kicad_pcb]
2025-05-27 adding text to back mask layer
    [TapOMatic_FrontPanel-B_Cu.gbr, TapOMatic_FrontPanel-B_Mask.gbr, TapOMatic_FrontPanel-B_Paste.gbr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]
2025-05-29 centered text on front panel
    [TapOMatic_FrontPanel-B_Cu.gbr, TapOMatic_FrontPanel-B_Mask.gbr, TapOMatic_FrontPanel-B_Paste.gbr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]
2025-05-29 more text fixes
    [TapOMatic_FrontPanel-B_Cu.gbr, TapOMatic_FrontPanel-B_Mask.gbr, TapOMatic_FrontPanel-B_Paste.gbr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]
2025-07-15 changing number of samples per block
2026-03-22 Code cleanup, messed with calibration (probably need testing), added lookahead dynamics management, tied read heads together to improve PSRAM cache performance, fixed panning so that it doesn't mess 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
    [TimeMachine.cpp, constants.h, dsp.h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]
2026-03-24 Attempting to further reduce noise and optimize CPU usage by doing some faster math, moving LED handling to while loop.
    [TimeMachine.cpp, dsp.h]
